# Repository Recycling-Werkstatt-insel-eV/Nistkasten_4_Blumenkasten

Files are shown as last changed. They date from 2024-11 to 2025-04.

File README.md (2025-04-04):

# Vogelhaus "Blumenkasten"
Dieses Vogelhaus verbindet gleich mehrere Funktionen: Zusätzlich zur der Nist-Möglichkeit für verschiedene Singvogelarten beinhaltet es einen weiteren Hohlraum für eine mögliche Bepflanzung und somit ein natürliches Schutz- und Futter spendendes Umfeld der Vögel. Zusammenstehende Behausungen können so angeordnet werden, dass sie ihre Pflanzen gegenseitig bewässern. Es gibt zudem verschiedene Variationen mit unterschiedlichen Einflugöffnungs- Formen und Größen, egal ob Höhlen- Halbhöhlen oder Freibrüter, wobei sich die jeweiligen Teile jederzeit unkompliziert austauschen lassen.

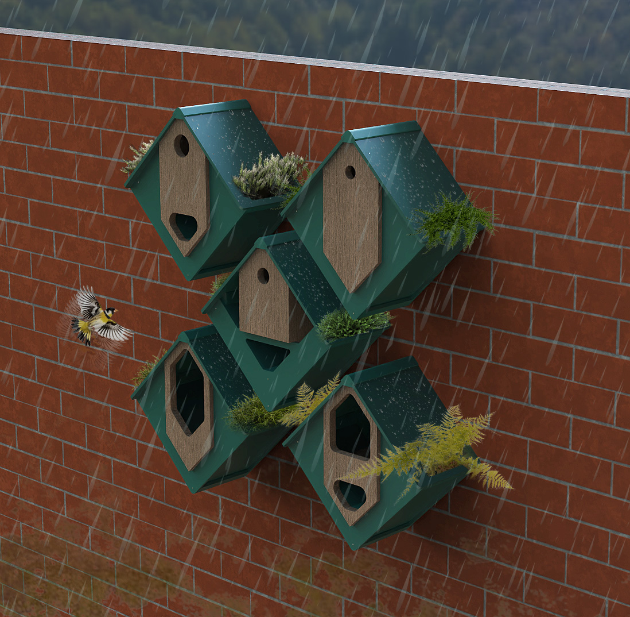
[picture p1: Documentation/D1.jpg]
 
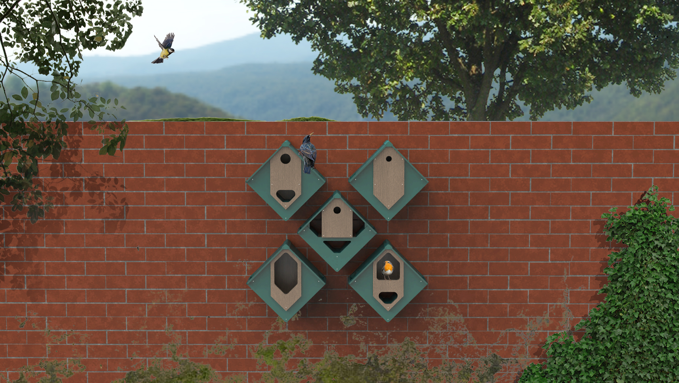
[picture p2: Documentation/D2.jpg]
 

__Du möchtest dieses Vogelhaus bauen?__

Dann hilft dir folgendes sich in dem Projekt zurechtzufinden: Zu Beginn ist es sinnvoll, dass du dir eine Übersicht durch die bereitgestellte [Checkliste](./Documentation/Checkliste.md) verschaffst. Was du an Materialien für benötigst, findest du in der [Materialliste](./Drawings/Materialliste_Vogelhaus_Blumenkasten.pdf). Anschließend kannst du dir die [Fertigungsanleitung](./Documentation/Anleitung_Fertigung.md) der einzelnen Komponenten ansehen. Je gewissenhafter du diese befolgt hast, desto einfacher wird im Anschluss der [Zusammenbau](./Documentation/Anleitung_Zusammenbau.md) der Behausung. Solltest du dir diese Infos bereits angeschaut und beschlossen haben, dass du das Vogelhaus weiterentwickeln möchtest, 
könnten dir die beigefügten [CAD-Dateien im STEP-Format](./CAD) und die [CAD- Dateien im STL-Format](./3D_printing/CAD_Blumenkasten_Vogelhaus.STL) hilfreich sein. 

# Allgemeines zum Projekt

Bei diesem Vogelhaus handelt es sich um einen von __4 Entwürfen__ aus einer Reihe innerhalb eines Projekts, in dem wir uns zur Aufgabe gemacht haben, kreative innovative und nachhaltige Ideen für Tierbehausungen zu finden und alte Lösungen zu überdenken. Unseren Fokus haben wir auf Vogelbehausungen gelegt. Und wer sind "wir"? Wir sind Menschen aus der Offenen [Recycling-Werkstatt von Insel e.V.](https://werkstatt.insel-ev.de/) in Hamburg. Besucht uns gerne auf unserer Website oder noch besser persönlich, wir freuen uns auf euch! 

Hier kommt ihr zur [Übersicht](https://github.com/Recycling-Werkstatt-insel-eV/Nistkasten_main_Uebersicht) der folgenden Entwürfe
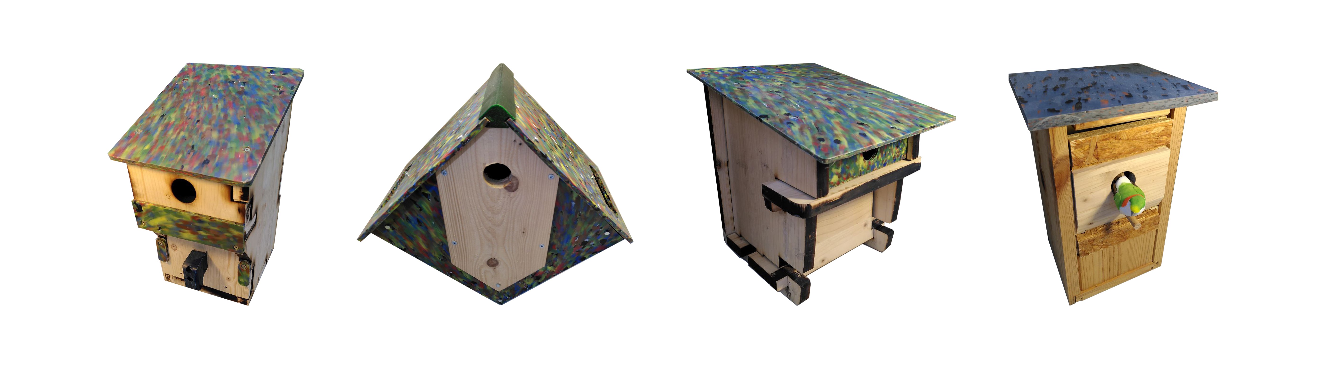
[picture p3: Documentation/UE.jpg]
 
Gefördert von der [Deutschen Stiftung Engagement und Ehrenamt](https://www.deutsche-stiftung-engagement-und-ehrenamt.de/foerderung/) haben wir im Laufe des Jahres 2024 zusammen mit Schüler_innen-Gruppen, Expert_innen vom [NABU](https://www.nabu.de/) und anderen klugen Köpfen getüftelt, wie wir Zeiten, in denen die Umwelt und Natur so schutzbedürftig wie noch nie sind, einen sinnvollen Beitrag leisten können. In Ideen- und Bau- Workshops sind dabei schlussendlich die 4 Konzepte entstanden und umgesetzt worden, die wir euch hier vorstellen wollen. 

__Und was macht unsere Entwürfe besonders?__
Besonders wichtig war uns unter anderem, dass die verwendeten Materialien möglichst nachhaltig sind und eingesetzt werden. Das heißt sie sollen wenig oder gar nicht neu produziert werden müssen. Wir wollen mit Dingen arbeiten, die es schon gibt und diese wieder aufbereiten und neu verwenden. Dafür haben wir in jedem Entwurf recycelten Kunststoff aus unserer Werkstatt verwendet. Dieser besteht aus geschredderten, geschmolzenen zu Platten gepressten Alltagsgegenständen, die sonst in den Müll gewandert wären. Außerdem sind alle Bestandtteile wieder voneinander trennbar. Es wurden keine Klebstoffe und nur wenige Schrauben verwendet. Modulare Systeme ermöglichen zusätzlich das Austauschen und ersetzen einzelner Bestandtteile, sodass die Vogelhäuser leicht repariert werden können und teilweise mehrere Funktionen und Varianten in einem Entwurf beinhalten.  

Aber wie das halt so ist... Kein Entwurf ist perfekt durchdacht. Und genau da kommt ihr ins Spiel. Wir wollen unser Projekt der Community zur Verfügung stellen und euch herzlich einladen die Vogelhäuser __nachzubauen, oder sogar weiterzuentwickeln__. Die Informationen, die  ihr genau dafür benötigt und wie ihr Schritt für Schritt vorgeht, findet ihr in den beiligenden Vogelhaus-Projekten. Von eher unkomplizierten Ideen, die mit einfachen Handwerkzeugen gefertigt werden können, bis hin zu gelaserten oder CNC- gefrästen z.T. herausfordernden Systemen ist für jede_n etwas dabei. Alles kann nichts muss und das gilt auch für die euch zur Verfügung stehenden Mittel. Von uns kommen einige gut gemeinte Ratschläge für die Umsetzung, fühlt euch jedoch gerne frei manches im Sinn eurer Möglichkeiten anders zu machen. Schaut euch gerne um ob und welches Vogelhaus etwas für euch ist, viel Spaß beim Bauen und weiterdenken!

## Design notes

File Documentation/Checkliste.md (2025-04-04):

# Checkliste

Unabhängig davon ob ihr eines der Vogelhäuser nachbaut, weiterentwickelt oder einen ganz neuen Entwurf kreiren und aufhängen wollt, gibt es einige wichtige Dinge zu beachten, die für die Umwelt, die Tiere und den Erfolg des Projekts mehr oder weniger wichtig sein können. 
Hier findet ihr eine Übersicht an Checkpunkten an denen wir uns oriententiert haben. 

__Schutz vor Nesträubern__

Viele Tierarten, insbesondere Vögel sind heutzutage stark bedroht. Neben anderen Faktoren sind Nesträuber wie Waschbären, Marder und Hauskatzen dafür verantwortwortlich. Um zu verhindern, dass diese Tiere die Brut der Singvögel bedrohen gibt es bewährte Maßnahmen:

1. Gestalte die Einflugöffnung gerade so groß, dass nur der Nistvogel und vergleichbargroße Arten durchpassen.
2. Baue einen vorgezogenen Zwischenboden in das Vogelhaus, (so wie wir es z.B. bei den Vogelhäusern Nr. 2 und Nr. 3 gemacht haben).
   In dieser Form haben die Räuber Schwierigkeiten bis zur Brut hinunter zu greifen. 
4. Bringe den Vogelkasten idealerweise in einer Höhe von mindestens 2 Metern an, sodass es manchen Räubern schwerer fällt die Brut zu wittern und 
diese zu erreichen.

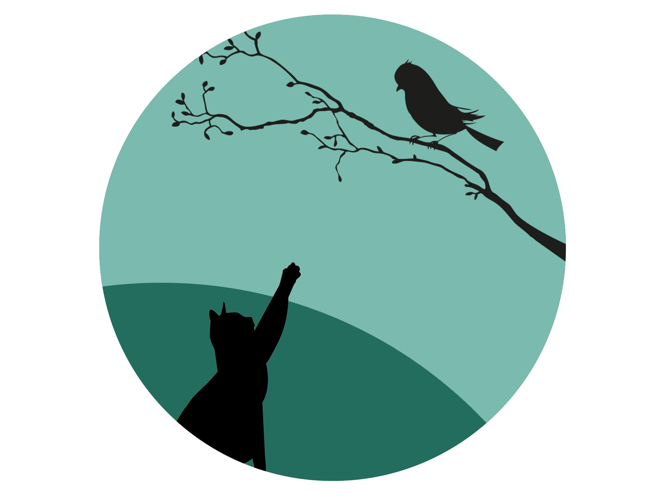
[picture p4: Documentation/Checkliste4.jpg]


__Der passende Ort__

Achte zudem darauf, dass du für dein Vogelhaus einen geeigneten Ort findest, wo sich die Tiere natürlicherweise wohl fühlen. 
Es sollte dort möglichst viel unterschiedliche Vegetation geben, die für viele Lebewesen einen Rückzugsort zum Verstecken und eine wichtige Nahrungsgrundlage bietet. Nur in einem gesunden Ökosystem siedeln sich auch Vögel an um dort zu brüten. Bei den beiden folgenden Beispielen sollte relativ klar ersichtlich sein, wo sich Tiere gut verstecken können und genügend Nahrung finden:  

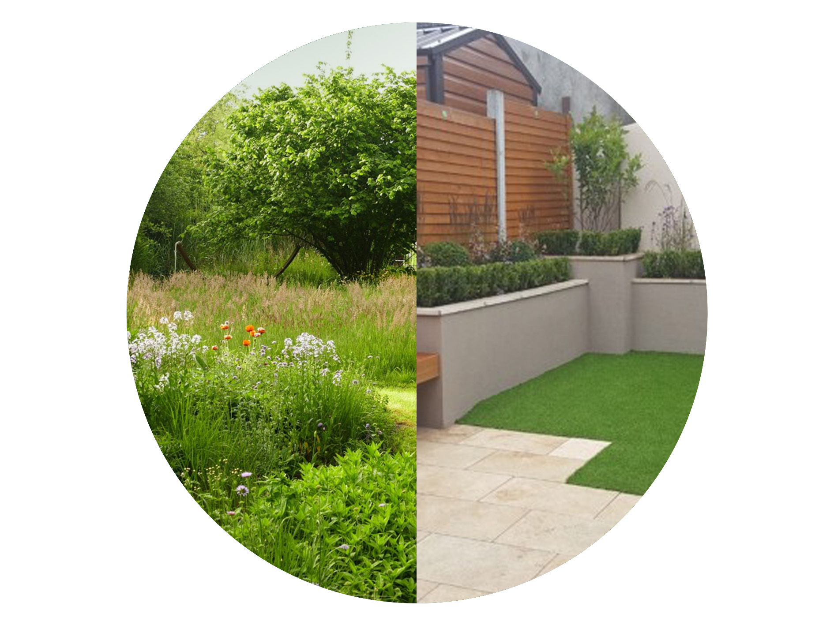
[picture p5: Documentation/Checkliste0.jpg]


__Die richtigen Maße__

Unter dem folgenden Link https://www.nabu-rlp-sued.de/artenschutz/bauanleitungen-f%C3%BCr-nisthilfen/ 
des Nabu Rheinland Pfalz findet ihr viele Infos zu dem Thema, auch die Maße für Vogelhäuser, welche sich etabliert haben um möglichst viele Vogelarten zu erreichen, indem sie gerade groß genug sind und entsprechend Material sparen. Es reicht aber wenn sie euch als ungefährer Anhaltspunkt dienen. 

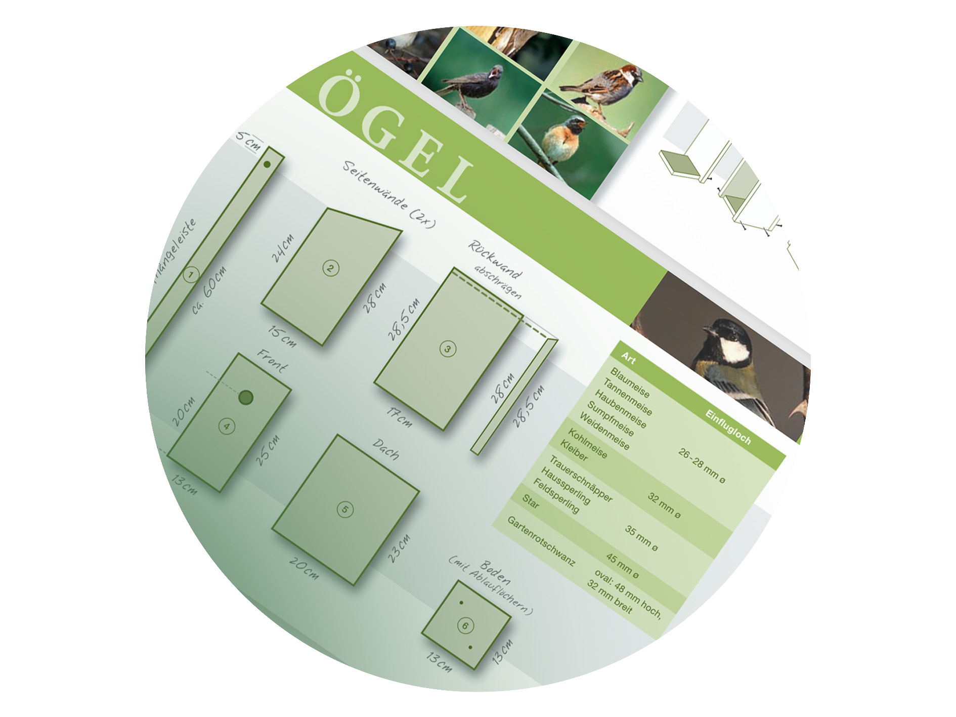
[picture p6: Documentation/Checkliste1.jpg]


__Reinigung des Nistkastens__

Leider müssen Nistkästen ein mal im Jahr nach der Brutsaison gereinigt werden, damit sie sich nicht mit Nistmaterial anfüllen und irgendwann nicht mehr bezogen werden. Gestalte den Kasten also idealerweise so, dass er sich unkompliziert öffnen und reinigen lässt. Die Brutsaison der meisten Singvögel ist im Frühsommer von Mai bis Juli. Ab August lohnt sich der erste Blick ins Innere ob der Mieter mitlerweile ausgezogen ist. 

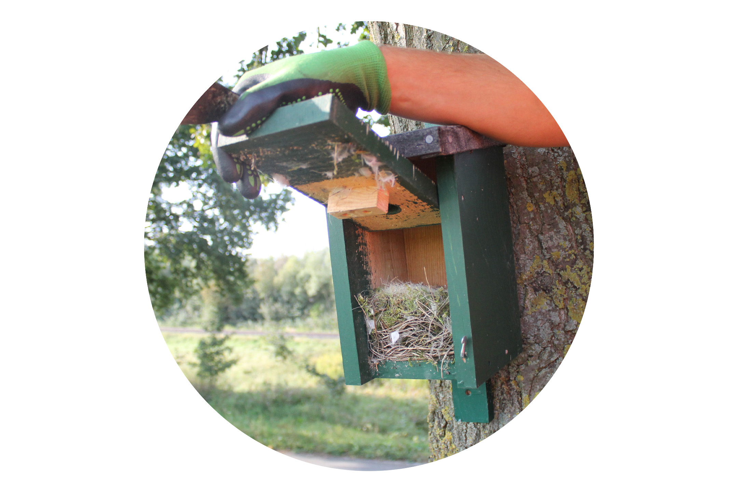
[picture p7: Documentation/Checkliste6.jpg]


__Die ideale Befestigung__

Einfache Eisen- oder Kupfernägel können für einige Baumarten problematisch sein, da sie für diese in einigen Fällen gesundheitsschädlich sind und der Pflanze schaden. Zudem gehen Werkzeuge wie Kettensägen beim Fällen der Bäume kaputt wenn sie in hartes Metall sägen. Um dies zu verhindern ist es ratsam Aluminium-Nägel zu verweden.   

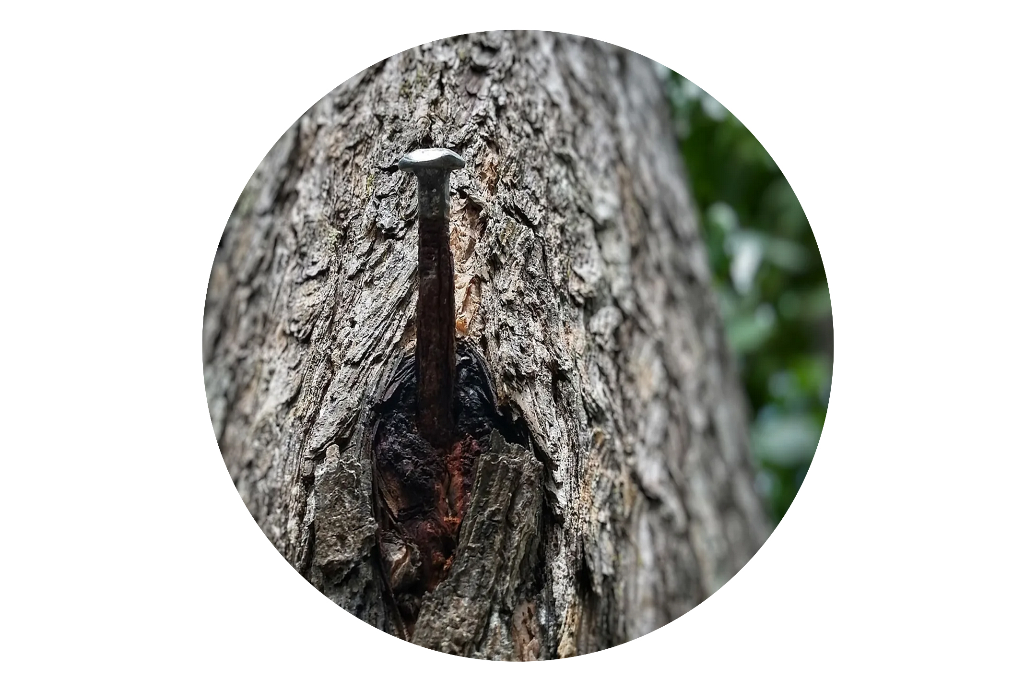
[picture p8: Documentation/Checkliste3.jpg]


__Geeignetes Material__

Die Materialwahl der Tierbehausung ist gleich aus mehreren Gründen besonders wichtig. Beachte dabei bitte folgende Punkte: 

1. Das Material sollte möglichst atmungsaktiv sein, denn wenn das Innere des Hauses mal nass wird und nicht richtig trocknet, kann sich Schimmel bilden, es setzen Fäulnisprozesse ein und Parasiten haben bei den Nestlingen leichteres Spiel. Das schadet der Gesundheit der Brut und verkürzt zudem die Langlebigkeit der Behausung.
2. Achte darauf, dass die verwendeten Materialien nicht vorbehandelt oder beschichtet wurden. In vielen Fällen verstecken sich giftige und umweltschädliche Chemikalien in und auf wiederverwerteten Gegenständen.
3. Denke an die Nachhaltigkeit deiner Materialien. Nachhaltig ist ein Material z.B. dann, wenn es sich mit der Zeit durch die äußeren Einflüsse natürlich zersetzt und komplett wieder in den biologischen Stoffkreislauf zurückgeführt werden kann. Versuche zudem möglichst keine neuen Materialien zu verwenden, sondern bereits existierende Werkstoffe neu aufzubereiten und wiederzuverwenden. Das klappt nicht immer, aber in vielen Fällen. Auch recycelter Kunststoff ist in eingen Fällen deutlich nachhaltiger als manche anderen Alternativen. Bspw. unsere Dächer bestehen aus wasserabweisendem Kunststoff um die Lebensdauer der Behausungen zu verlängern. 

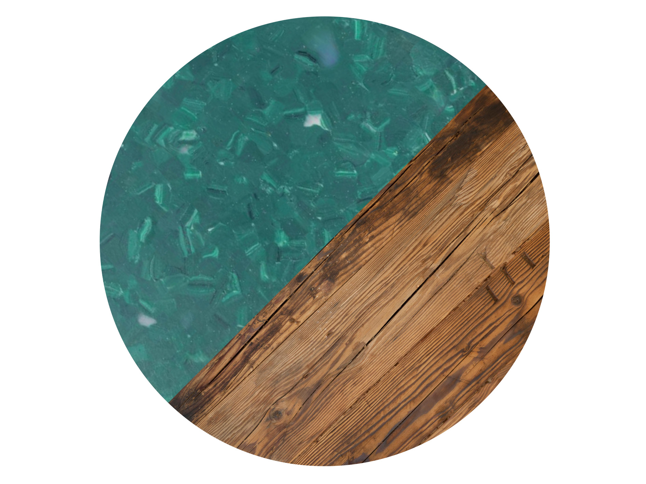
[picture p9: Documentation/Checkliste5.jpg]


Wenn du möglichst viele dieser Punkte beachtest, hast du in deinem Vorhaben schon halb gewonnen.

__Viel Spaß bei der Umsetzung!__

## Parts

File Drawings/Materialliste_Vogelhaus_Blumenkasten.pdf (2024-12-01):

Materialliste Vogelhaus "Blumenkasten"

Bezeichnung | Material | Anzahl | Maße/Typus | Beschreibung/Anmerkungen
Rohling Holzbrett | Massivholz aus Fichte, Kiefer, Lärche oder vergleichbarem Nadelholz vorzugsweise Altholz oder eine andere nachhaltige Alternative. | Min. 1 | 1200/150/18 mm | Die Maße beziehen sich auf die Annahme, dass alle Holzteile aus einem Bauteil gearbeitet werden. Es können auch mehrere einzelne Bretter verwendet werden. Die Dicke sollte maximal um 1 mm variieren. Siehe Einzelbemaßungen „Maße Holzteile“
Rohling Kunststoff-teile | Kunststoff z.B. PE (Polyethylen) oder PP (Polypropylen) möglichst aus nachhaltiger Herstellung/ Weiterverwendung | Min. 1 | 1000/550/7 mm | Siehe Einzelbemaßungen „Maße Kunststoffteile“
Schrauben | Metall (Stahl oder Messing gerne verzinkt oder veredelt um die Langlebigkeit zu gewährleisten) | 14 10 | Typ M3 Durchmesser: 3 mm Länge: 20-22 mm Typ M3 Durchmesser: 3 mm Länge: 38-42 mm | Es ist genau zu beachten welche der beiden Schraubenlängen an welcher Stelle verwendet wird. Siehe Bau- Anleitungs- Schritte.
Hilfs-Schablone | MDF, HDF oder Leimholz o.ä. Möglichst nachhaltigste aber stabile Alternative. | 1 | 800/320/3-5 mm | Das Material sollte möglichst dünn sein um durch die ausgelaserten Linien mit einem Bleistift zeichnen zu können, gleichzeitig aber bruchfest und mit einem Laser bearbeitbar sein. Das Bauteil kann auch CNC-gefräst werden. Digitale Fertigung ist allgemein ratsam wegen komplizierter Bemaßung. Wenn die Bauteile entsprechend der gewählten Variante direkt gefertigt werden ist die Schablone aber nicht zwingend notwendig.

Nägel/ Schrauben mit Dübeln | Aluminium oder anderes Metall | ca. 3-4 | 3mm Durchmesser min. 30 mm Länge | Zur Befestigung der Konstruktion an einem Objekt werden entweder Nägel oder Schrauben (ggf. mit Dübeln) verwendet, abhängig vom Material an dem sie befestigt wird.
3D Druck – Filament | Holzfilament/ Bambusfilament , PLA (Polyactid), rPLA (recyceltes PLA) oder andere nachhaltigere Alternativen | 1 | Ca. 69 Meter bei 1,75 mm Durchmesser | Die benötigte Länge variiert mit der Art des Filaments. Sie für die Vorlage der Teile die beigefügte STL Datei „3D Druck Komponenten“ Bei kleineren Druckbetten müssen die Teile einzeln gedruckt werden. Zusätzlich ist eine Version dieses Vogelhauses beigefügt, welche ohne 3D Druck Komponenten auskommt. Achtung: Dort variieren die Maße der anderen Teile zu dieser Version. (siehe„Vogelhaus_Blumenkasten_ ohne 3D_Druck_Komponenten“)

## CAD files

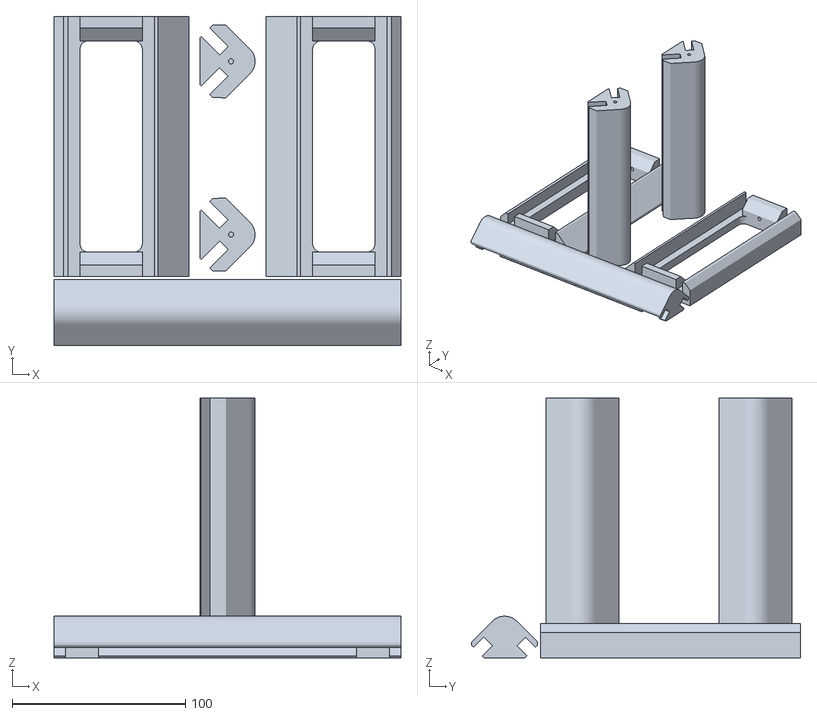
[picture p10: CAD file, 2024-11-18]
3D_printing/STL_3D_Druck_Komponenten.STL
200.0 x 189.8 x 150.0

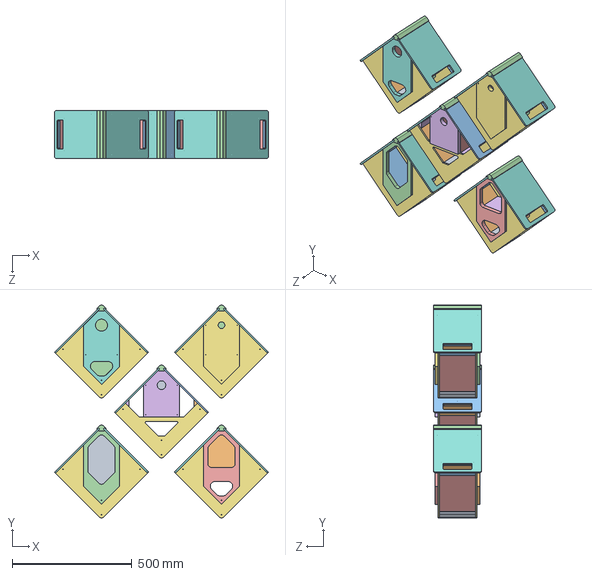
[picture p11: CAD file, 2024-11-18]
CAD/CAD_Blumenkasten_Vogelhaus.STEP
891.7 x 887.6 x 200.0 mm

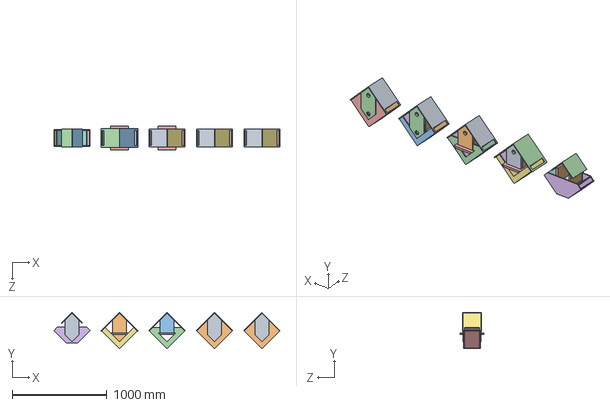
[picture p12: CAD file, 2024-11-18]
CAD/CAD_Blumenkasten_Vogelhaus_ohne_3D_Druck_Preversion.STEP
2379.2 x 380.6 x 250.0 mm

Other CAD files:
3D_printing/CAD_Blumenkasten_Vogelhaus.STL

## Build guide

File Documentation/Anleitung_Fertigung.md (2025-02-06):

# Anleitung zur Fertigung der einzelnen Bauteile

Hier und im folgenden ist beschrieben wie beim Bau von Vogelhaus "Blumenkasten" idealerweise vorgegangen werden kann. Ergänzende Infos und Kaufvorschläge der Materialien sind unter "Drawings", "Materiallsite_Vogelhaus_Blumenkasten" zu finden. 

__Schritt 1__ Fertigung der Holzteile

Die Holzteile können aus einem einzelnen Werkstoffteil (1200/150/18mm) oder mehreren Brettern gefertigt werden. Entscheidend ist die Materialstärke von 18 mm (+-0.5 mm). Da auch schräge Schnitte notwendig sind sollten diese Komponenten mit einer Tischkreissäge, Tauchsäge oder Formatkreissäge umgesetzt werden.  
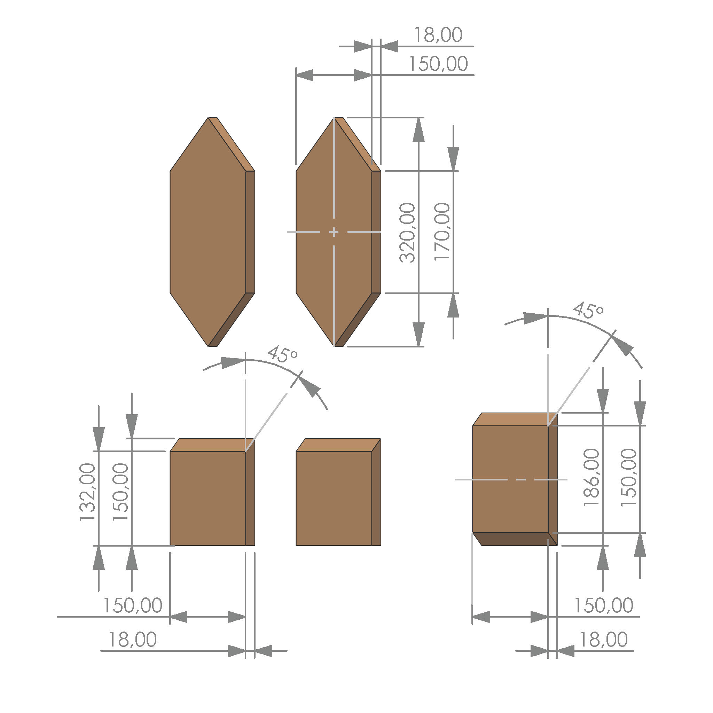
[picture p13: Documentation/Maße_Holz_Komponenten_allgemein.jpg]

__Schritt 2__ Fertigung der Kunststoffteile 

Um die Rohlinge der Kunststoffteile zuzuschneiden wird eine Platte der Größe 1000/550/7 mm oder mehrere einzelne benötigt. 
Entscheidend ist auch hier die Materialstärke von 7 mm (+- 0.5 mm) Da besonders hier sehr maßgenau gearbeitet werden muss, ist eine Nachbearbeitung der Teile nicht ausgeschlossen. Idealerweise sollten diese Komponenten mit einer Tischkreissäge, Tauchsäge oder Formatkreissäge umgesetzt werden.   
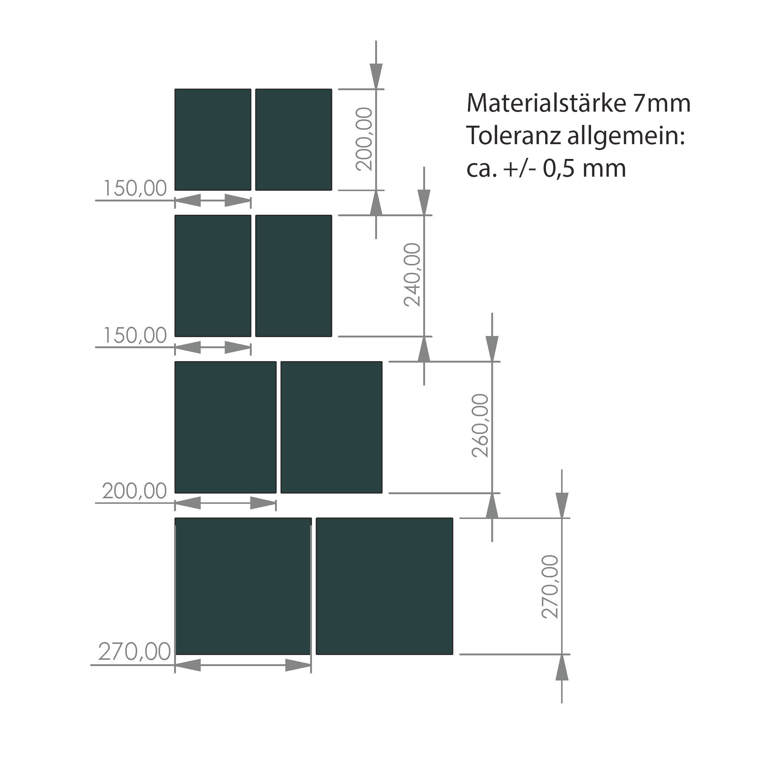
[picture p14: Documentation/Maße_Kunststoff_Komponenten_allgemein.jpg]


__Schritt 3__ Fertigung der 3D Druck Teile 

Im Ordner 3D_Printing ist eine Datei mit dem Namen "STL_3D_Druck_Kompnenten" zu finden. Um alle 3D Druck Profile wie dort in einem Rutsch zu drucken muss der Drucker ein Druckbett mit einer eine Fläche von mindestens 200/250 mm aufweisen und auf 200 mm Höhe drucken können. Die einzelnen Komponenten können natürlich auch einzeln gedruckt werden. Das verwendete Material sollte wetterbeständig, formstabil und idealerweise möglichst nachhaltig sein. Die Anordnung Ausrichtung der Teile für ein ideales Ergebnis ohne Stützmaterial und entsprechend überflüssige Nachbarbeitung sieht wie folgt aus: 

Du findest die entsprechende 3D-Druck Datei [hier](../3D_printing/STL_3D_Druck_Komponenten.STL)
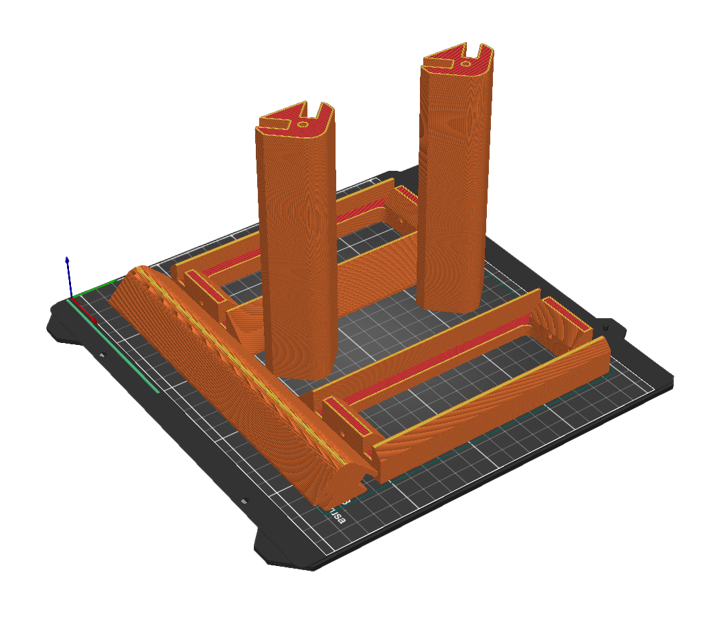
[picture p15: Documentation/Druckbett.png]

__Schritt 4__ Fertigung der Varianten- Schablone 

Im Ordner "Drawings" findet ihr neben den Bemaßungen auch eine SVG Datei namens "Laser_Schablonen.svg" Ihr könnt die Datei nutzen um Schablonen herzustellen, die es euch möglich machen die Konturen der 5 Varianten (V1-V5) mit einem spitzen Bleistift durch die ausgelaserten Linien nachzuzeichnen. Habt ihr die Schablone also einmal gefertigt, lässt sich jede der Varianten deutlich einfacher umsetzen, als jede Linie einzeln anzuzeichnen. Diese sieht in etwa so aus:   
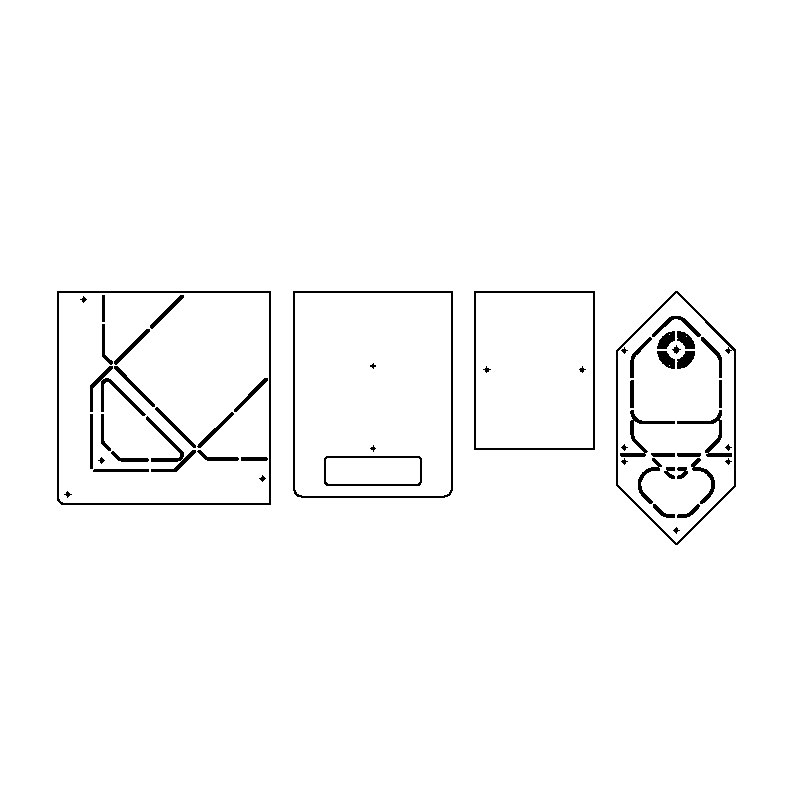
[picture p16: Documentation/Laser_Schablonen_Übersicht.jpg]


Alle Schablonen lassen sich gemeinsam aus einer Platte der Größe 800/320 mm ausschneiden. 
Das ideale Material ist MDF oder HDF mit einer Dicke von 3-5 mm. Auch Leimholzplatten sind denkbar, jedoch etwas weniger stabil. Einige Kuststoffsorten kommen ebenfalls in Frage.  Grundsätzlich gilt es aber ein Material zu wählen, dass überhaupt mit Industrielasern bearbeitet werden kann. Nicht geeignet, weil leicht entflammbar und gesundheitsschädlich sind bspw. PVC u. PVB. Es ist wichtig sich vor der Materialwahl und Umsetzung genauer über die entsprechenden Sicherheitsvorschriften zu informieren. 

Du findest die Schablonensammlung [hier](../Drawings/Laser_Schablonen.svg) 
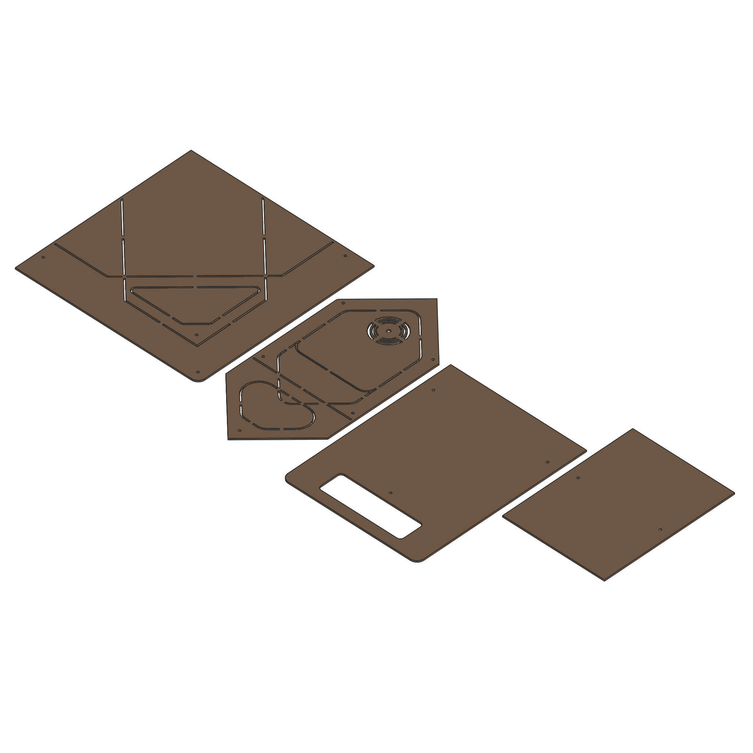
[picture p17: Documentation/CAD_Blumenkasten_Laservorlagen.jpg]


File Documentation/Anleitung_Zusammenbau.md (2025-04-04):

# Aufbauanleitung

Hier findet ihr die Bauanleitung von Vogelhaus "Blumenkasten". Achtet darauf, dass ihr alle entsprechenden Einzelteile im Voraus gefertigt habt, bevor ihr versucht die Teile zusammenzusetzen. Die Reihenfolgenach dem folgenden Prinzip ist bindend damit der Zusammenbau einfach und fehlerfrei abläuft. Die folgende Anleitung wurde konkret für die Variation "V2" erstellt, sie funktioniert jedoch auch stellvetretend für die anderen Beispiele V1-V5. 

__Benötigte Werkzeuge und Hilfsstoffe für den Zusammenbau__

1. Schraubendreher oder Akkuschrauber
2. Schraubzwingen oder eine helfende Person
3. Schleifpapier (Körnung 80-200) oder Holzpfeilen für Korrekturen oder abschließende Schönheitsarbeiten.  

__Variationen V1-V5 Frontansicht außen__
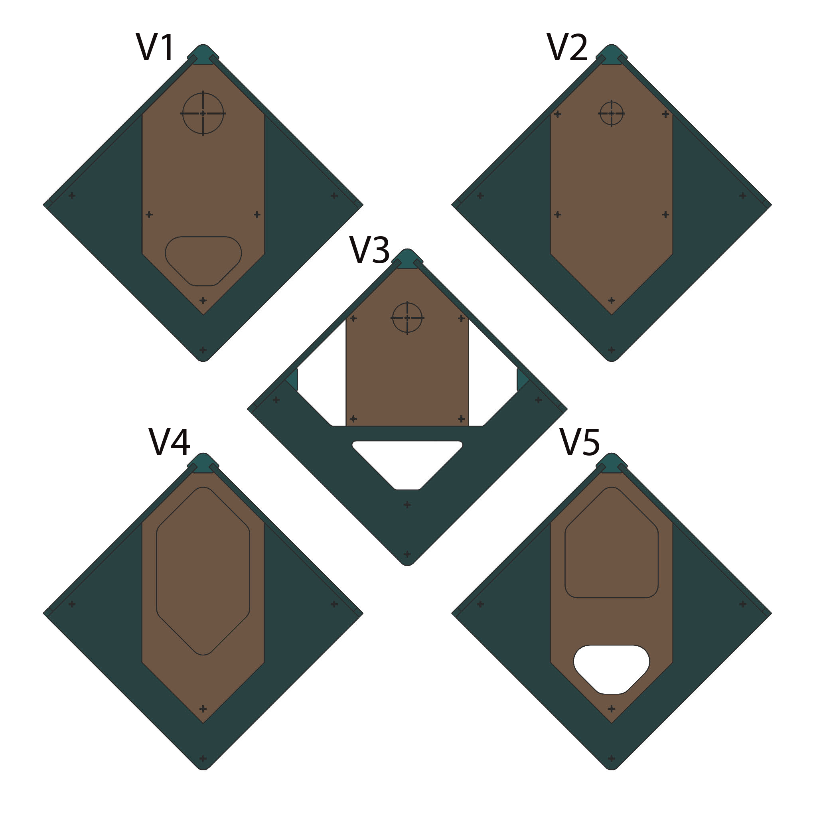
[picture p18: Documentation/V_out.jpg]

__Variationen V1-V5 Frontansicht innen__
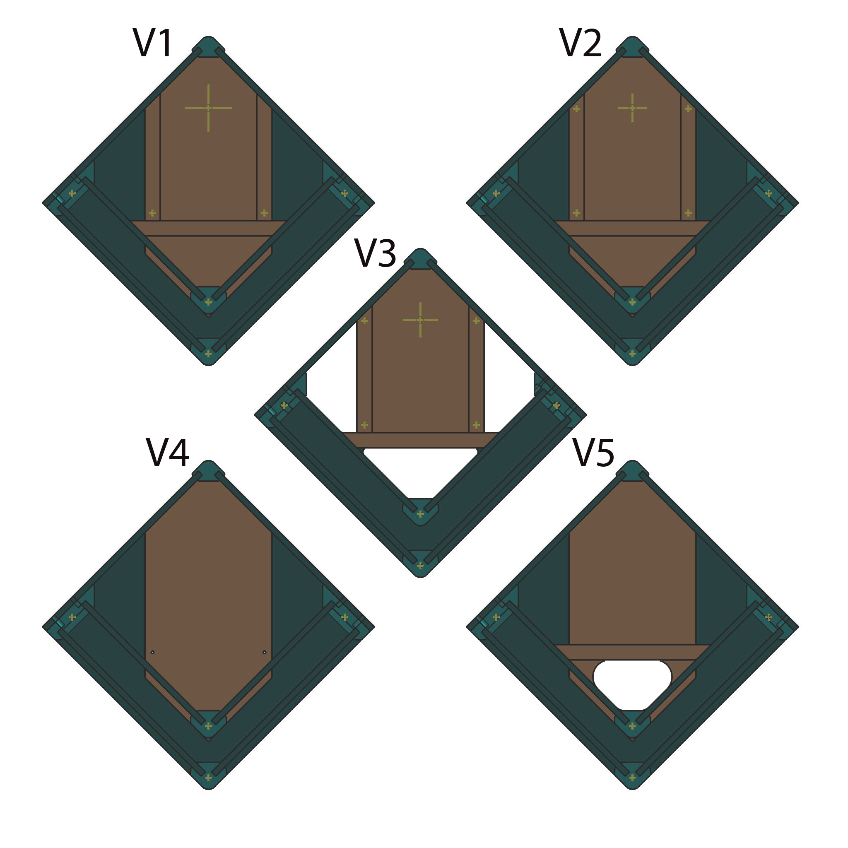
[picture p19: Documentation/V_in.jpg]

__Benennung der Teile__ 

Um die teilweise ähnlichen Teile für den Zusammenbau bestimmen zu können sind diese folgendermaßen benannt worden: 

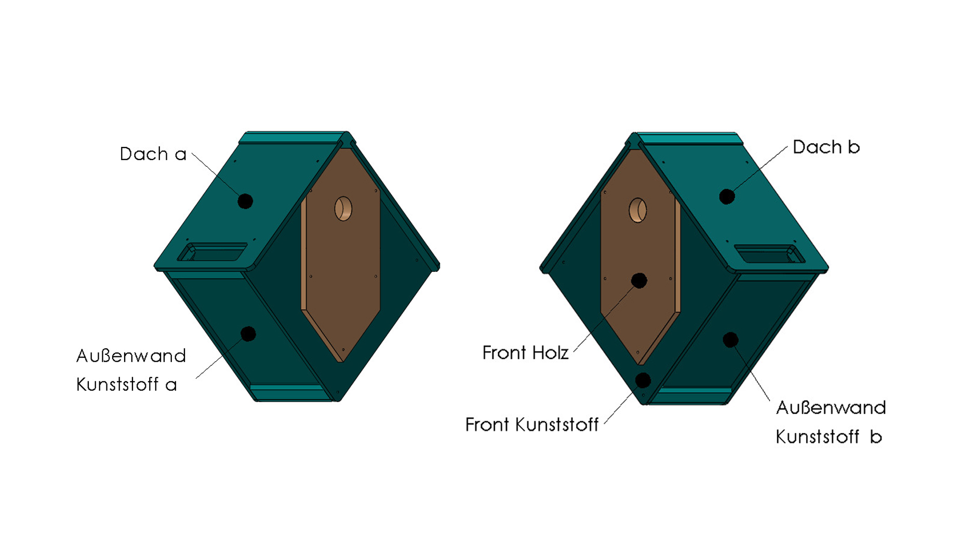
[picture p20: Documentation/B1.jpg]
 
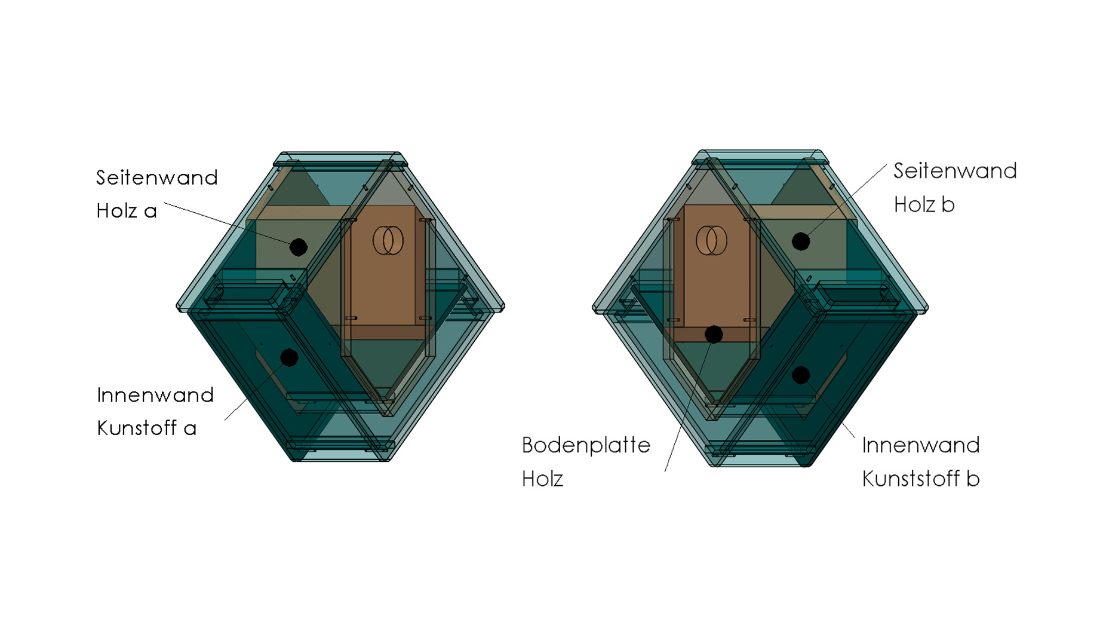
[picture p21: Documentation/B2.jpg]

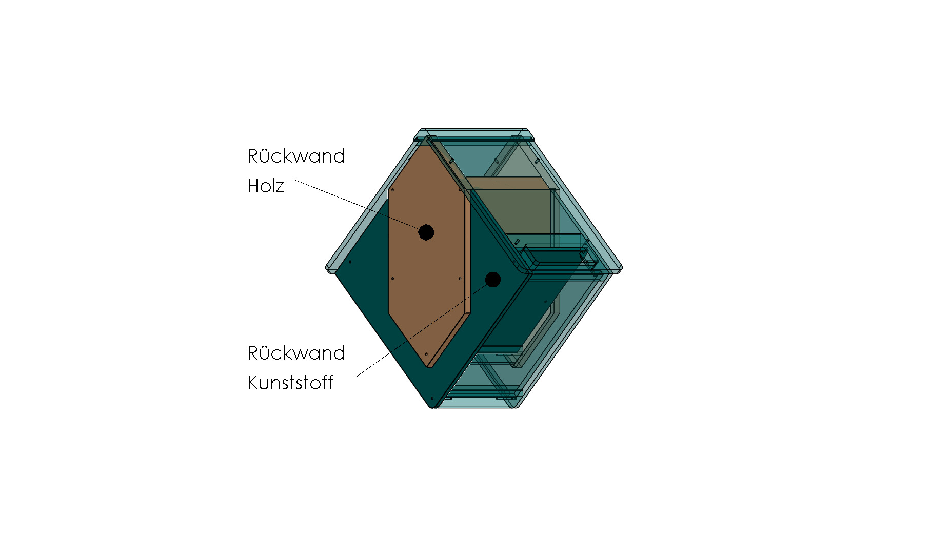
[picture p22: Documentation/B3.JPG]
 
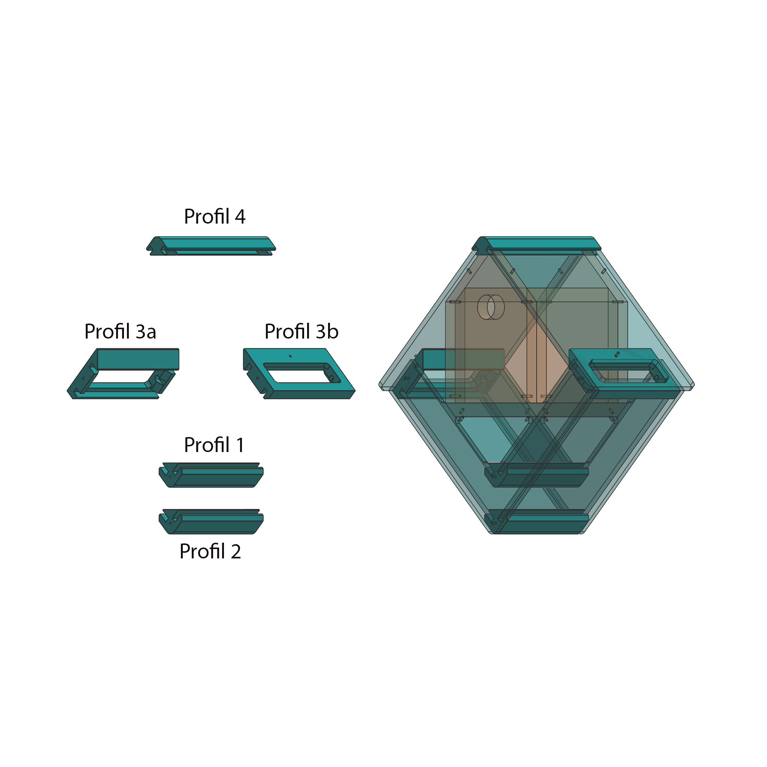
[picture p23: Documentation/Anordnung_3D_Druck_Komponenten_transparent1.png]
 
__Baugruppe 1/3__ 

__Schritt 1__
Schiebe die Teile "Frontwand Holz" und "Rückwand Holz" mit den beiden "Seitenwänden a und b"  wie folgt zusammen und fixiere sie beidseitig mit jeweils 4 der M3 Schrauben der Länge 38-42 mm. Tipp: Du kannst die Teile mit Schraubzwingen oder einem Schraubstock zuvor in Position halten. Achte grundsätzlich darauf, dass die Teile möglichst bündig und in richtiger Postition zueinander stehen! 
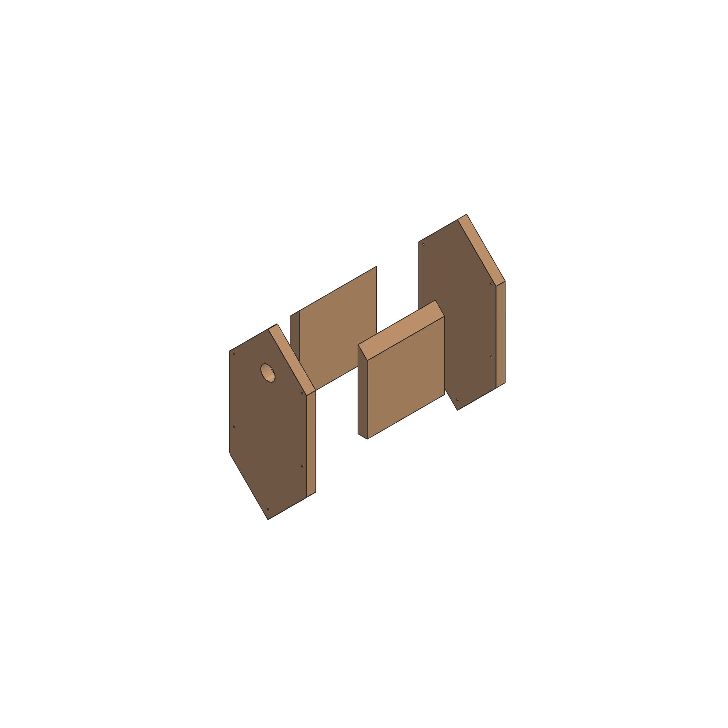
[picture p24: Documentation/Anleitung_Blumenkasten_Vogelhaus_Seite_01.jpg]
 
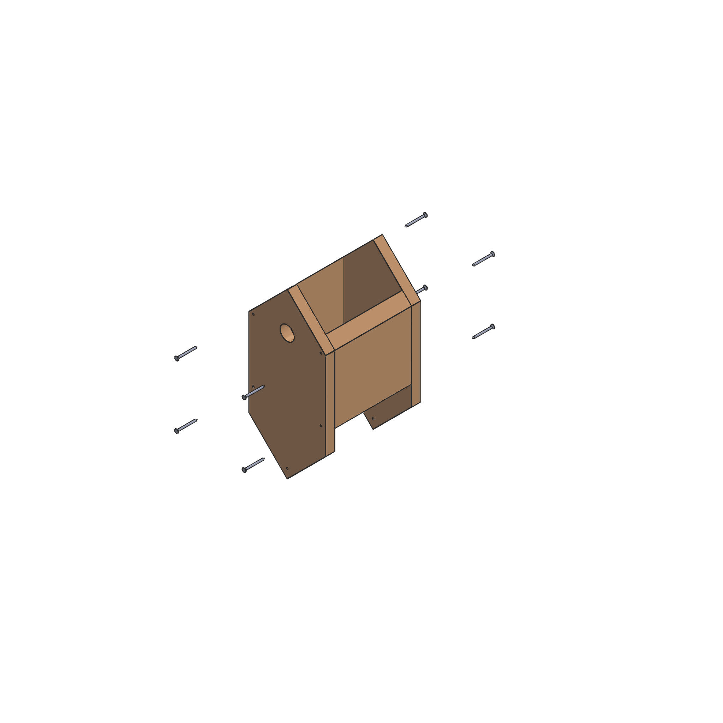
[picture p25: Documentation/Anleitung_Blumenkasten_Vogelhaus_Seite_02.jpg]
 
__Schritt 2__ Ergänze nun das untere 3D Druck "Profil 1" und fixiere dies mit beidseitig mit 2 M3 Schrauben der Länge 38-42 mm. 
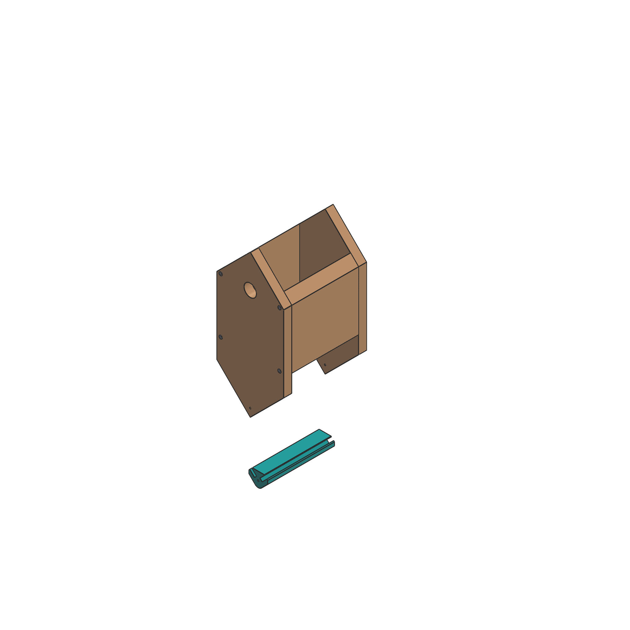
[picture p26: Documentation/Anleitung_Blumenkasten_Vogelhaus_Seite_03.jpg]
 
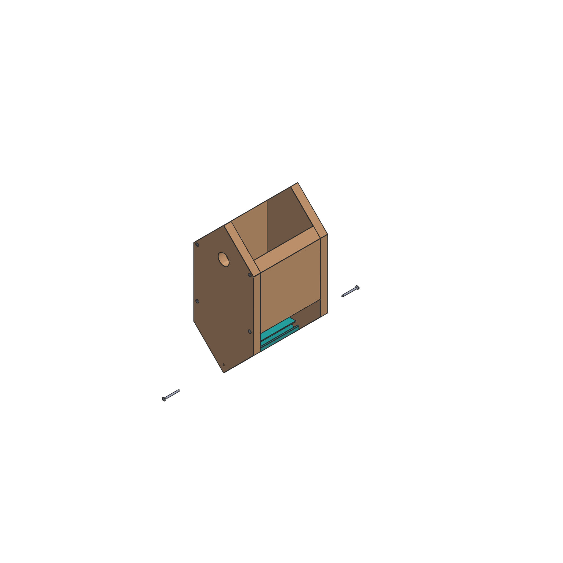
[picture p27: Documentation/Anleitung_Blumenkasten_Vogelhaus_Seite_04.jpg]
 
__Schritt 3__ Schiebe das Teil "Bodenplatte Holz" des Hauses seitlich in die entstandene Lücke. 
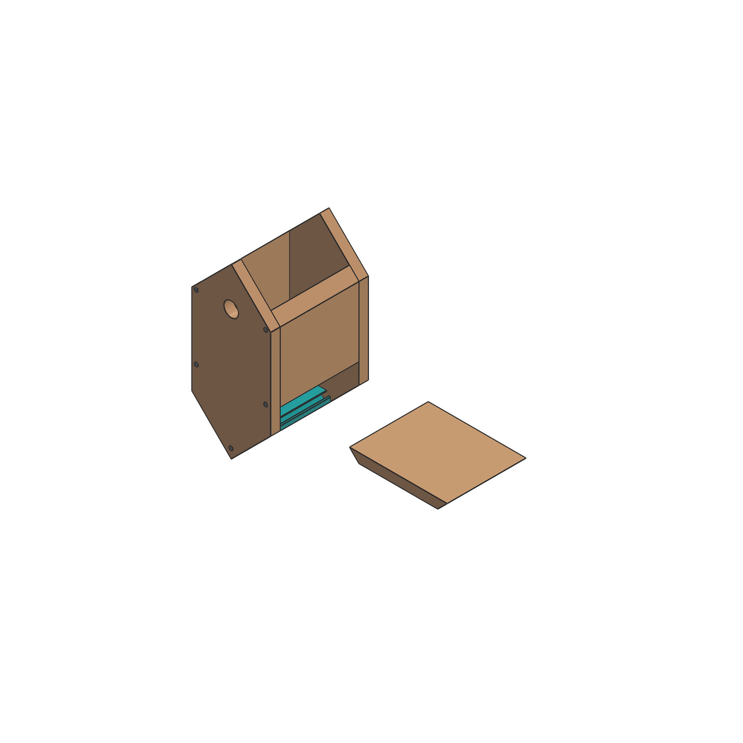
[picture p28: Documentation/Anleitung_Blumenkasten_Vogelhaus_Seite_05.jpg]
 
__Schritt 4__ Nun schiebe wie folgt die beiden "Innenwände Kunstoff" (200 x 150 m) schräg hinein. Achte darauf, dass die beiden Teile bis zum Anschlag in dem unteren 3D Druck "Profil 1" einrasten. Nun fixiere die Teile durch die vorgesehenen Löcher mit jeweils 2 Schrauben M3 der Länge 20-22 mm.  
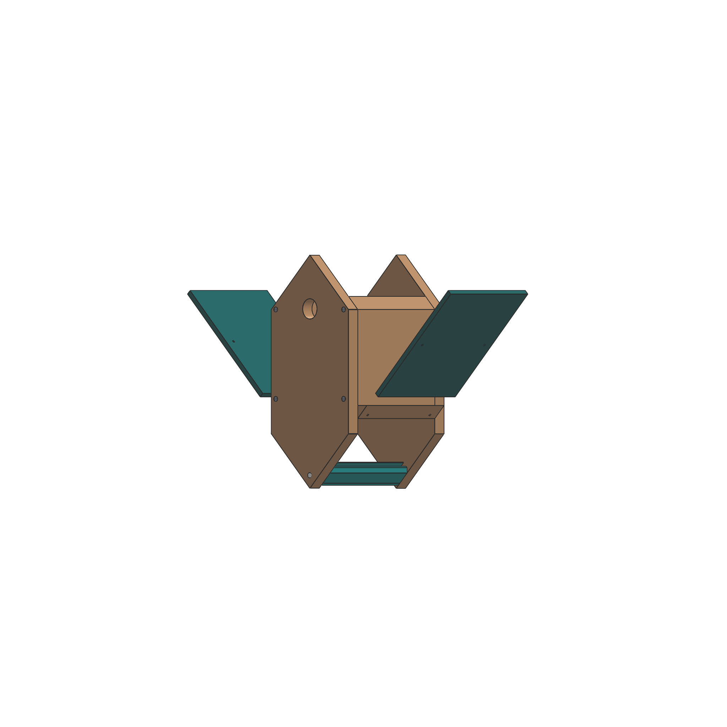
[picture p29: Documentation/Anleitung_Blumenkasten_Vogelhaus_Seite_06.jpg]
 
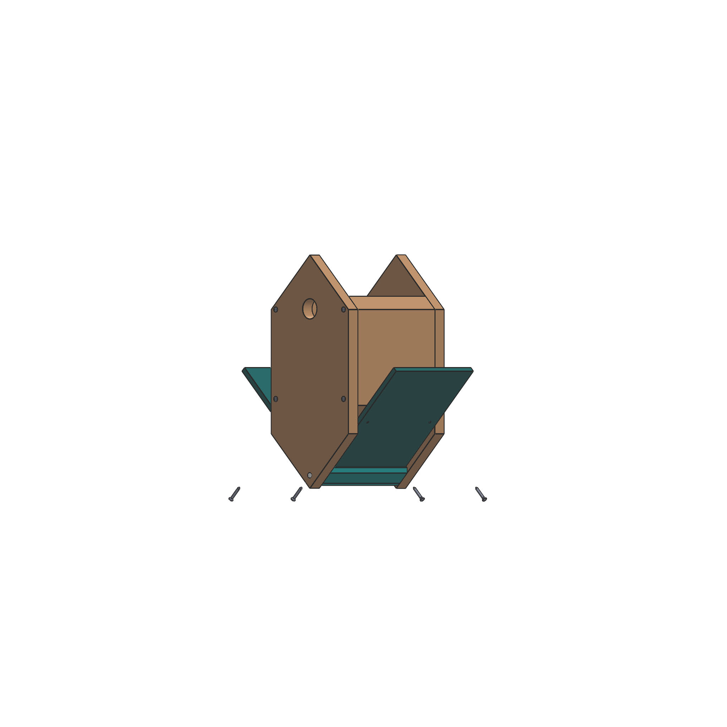
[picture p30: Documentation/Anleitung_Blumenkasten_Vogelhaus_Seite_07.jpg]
 
__Baugruppe 2/3__

__Schritt 5__ Schiebe nun die äußeren "Seitenwände Kunststoff a und b" in das 3D Druck "Profil 2". 
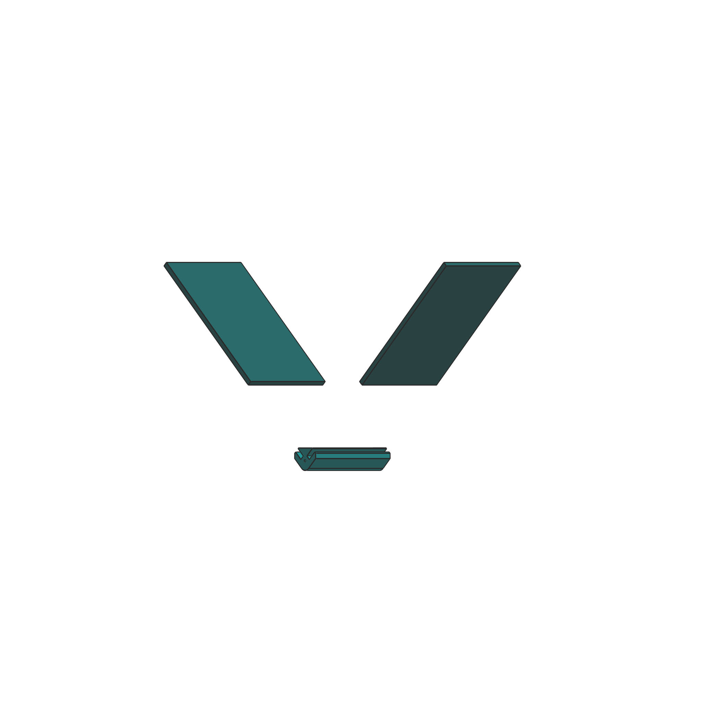
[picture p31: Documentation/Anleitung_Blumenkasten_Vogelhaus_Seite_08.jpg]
 
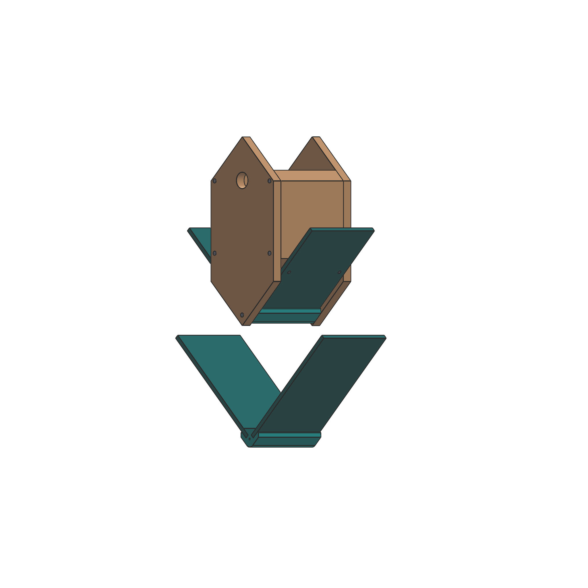
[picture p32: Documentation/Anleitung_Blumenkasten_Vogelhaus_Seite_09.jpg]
 
__Schritt 6__ Setze nun beide Baugruppen zusammen, indem du die 3D Druck "Profile 3a und 3b" folgendermaßen positionierst: 
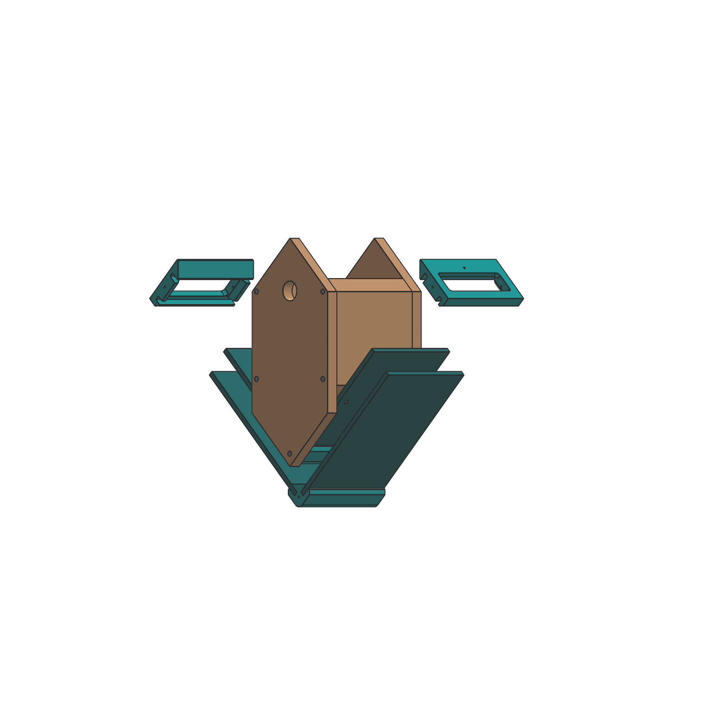
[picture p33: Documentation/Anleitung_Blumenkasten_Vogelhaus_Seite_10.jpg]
 
__Schritt 7__ Nun werden die "Front Kunststoff" und "Rückwand Kunststoff" angesetzt. Diese werden mit jeweils 3 M3 Schrauben der Länge 20-22 mm befestigt. 
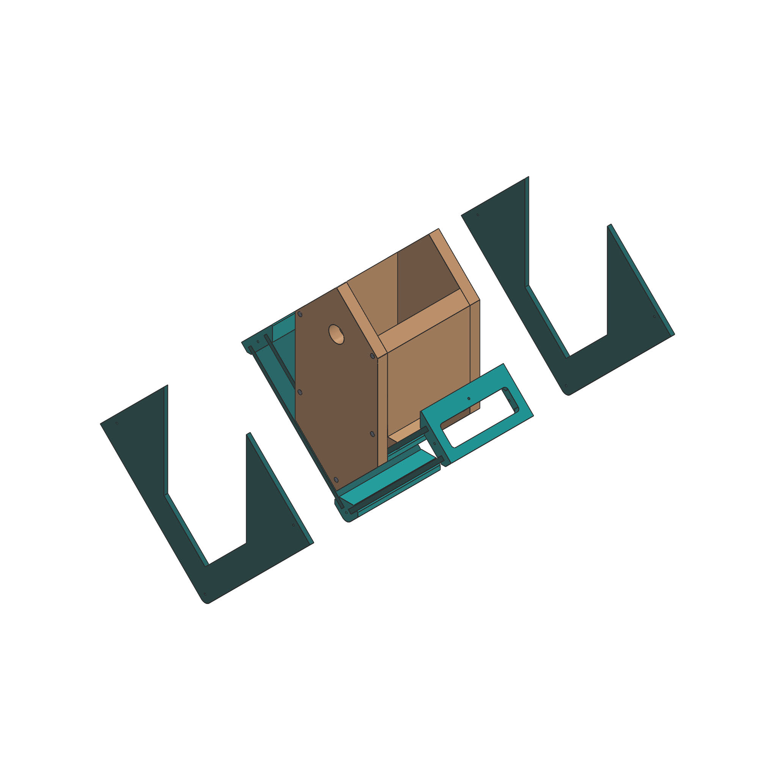
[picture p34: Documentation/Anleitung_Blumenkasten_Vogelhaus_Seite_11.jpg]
 
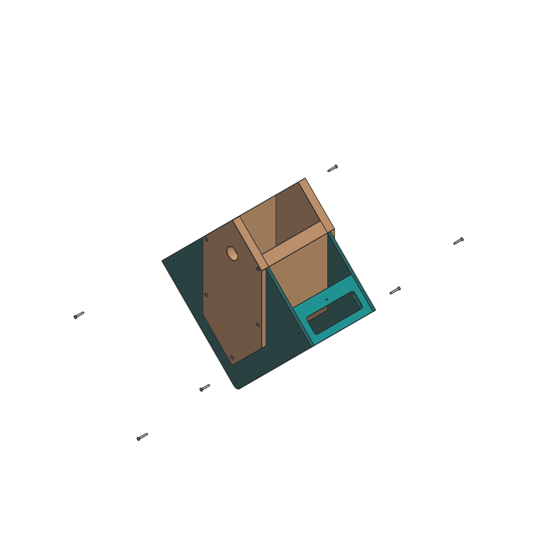
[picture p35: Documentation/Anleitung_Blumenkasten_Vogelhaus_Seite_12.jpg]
 
__Baugruppe 3/3__

__Schritt 8__ Füge nun die beiden Teile "Dach a und b" aus Kunstoff mit 3D Druck-"Profil 4" zusammen.
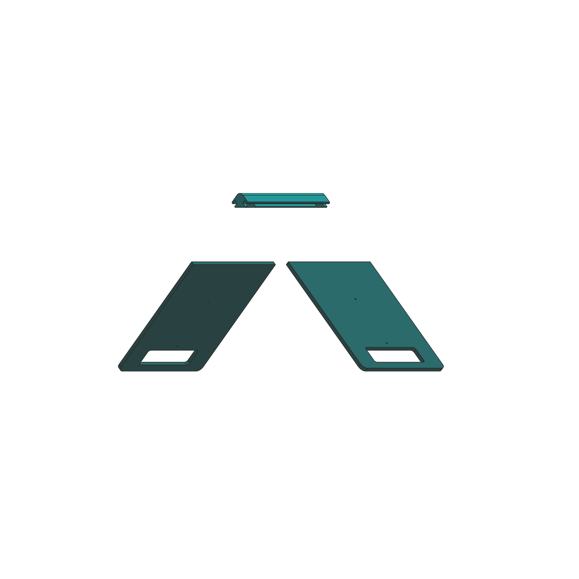
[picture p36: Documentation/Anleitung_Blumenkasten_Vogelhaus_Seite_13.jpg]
 
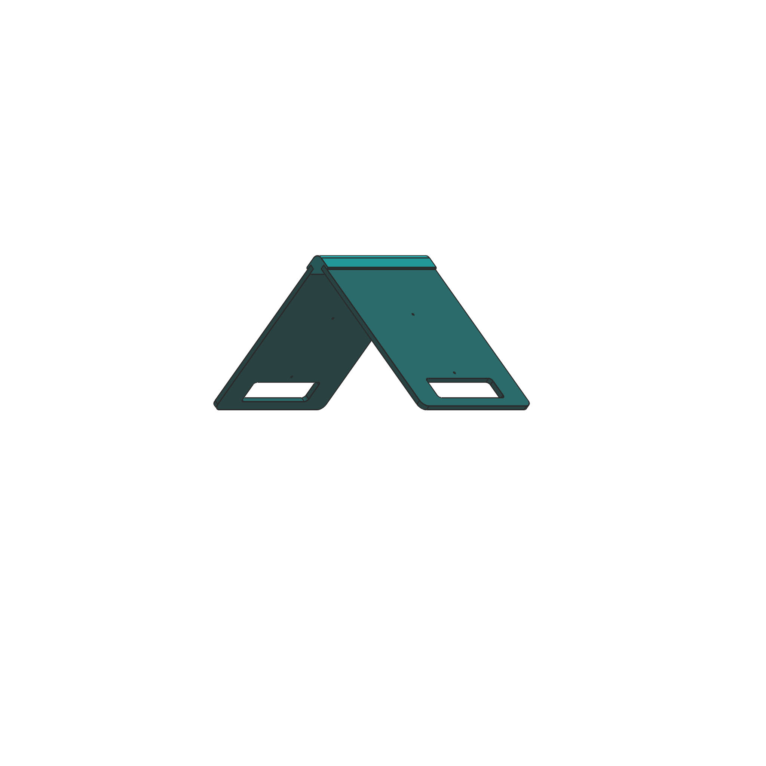
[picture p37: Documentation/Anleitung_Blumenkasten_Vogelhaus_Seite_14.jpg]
 
__Schritt 9__ Setze nun Baugruppe 1/2 und Baugruppe 3 zusammen. Zur Befestigung benötigst du beidseitig jeweils 2 M3 Schrauben der Länge 20-22 mm
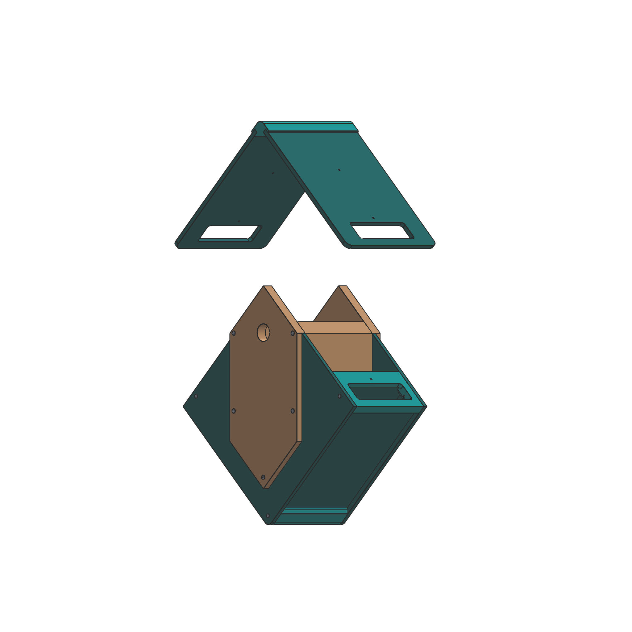
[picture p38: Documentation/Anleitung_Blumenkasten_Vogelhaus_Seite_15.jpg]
 
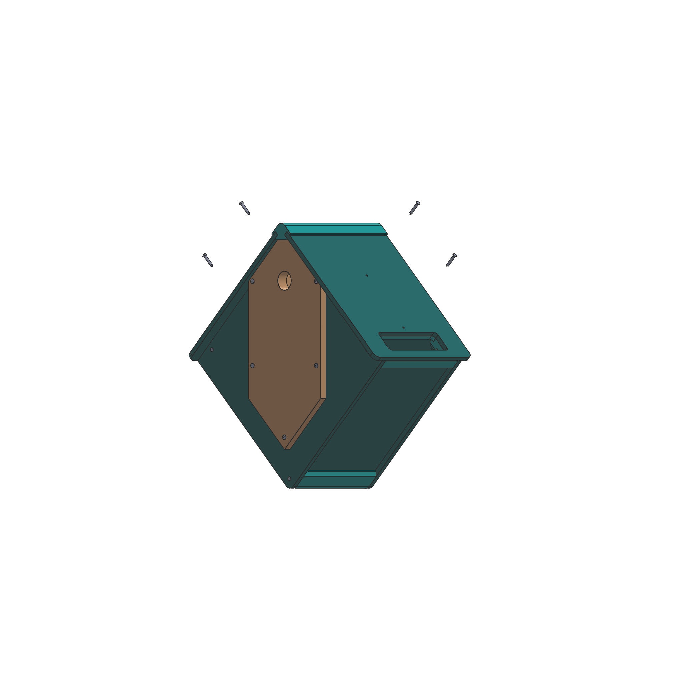
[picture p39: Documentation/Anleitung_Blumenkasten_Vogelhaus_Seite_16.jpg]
 
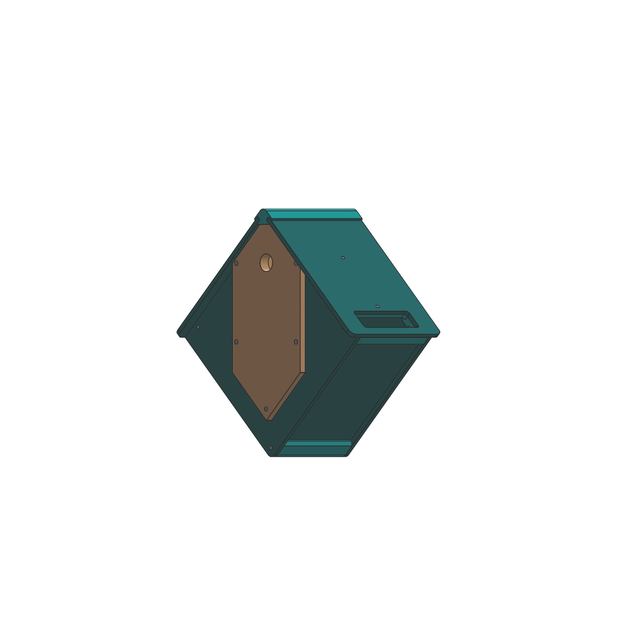
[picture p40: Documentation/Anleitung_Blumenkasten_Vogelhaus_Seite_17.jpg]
 
__Fertig__ Herzlichen Glückwunsch, du hast es geschafft! Jetzt musst du das Vogelhaus nur noch montieren. Bohre hierfür abschließend Löcher nach deinen eingenen Vorstellungen in die Rückwand des Hauses und befestige dieses mit Haken oder Bändern entsprechend deinen Vorstellungen.
